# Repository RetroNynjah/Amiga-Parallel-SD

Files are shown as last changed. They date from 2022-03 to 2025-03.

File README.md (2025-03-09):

# Retroninja Amiga Parallel SD

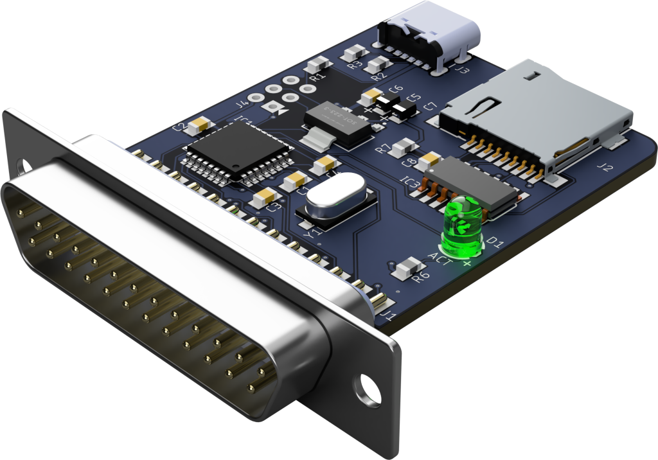
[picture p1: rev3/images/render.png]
Render
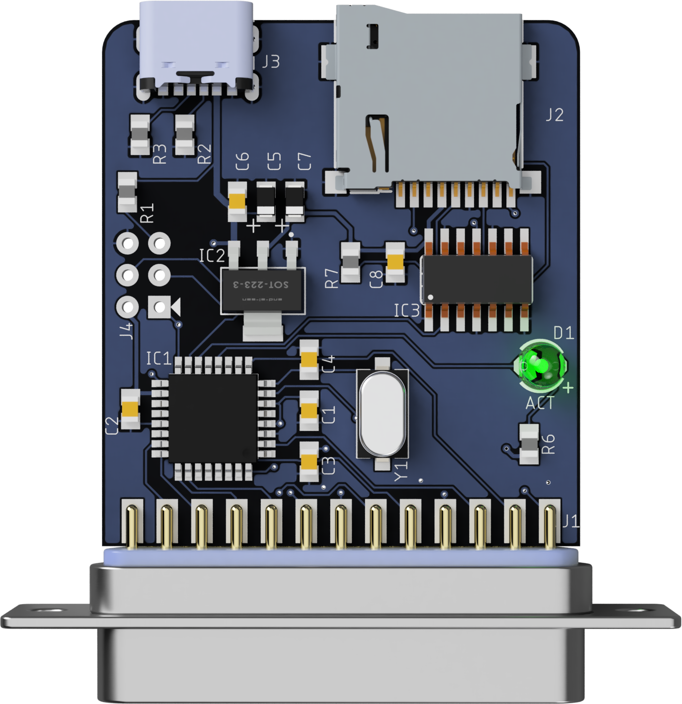
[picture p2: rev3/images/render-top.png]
Render top
<br/>

MicroSD SPI interface based on a design concept by [Niklas Ekström](https://github.com/niklasekstrom/amiga-par-to-spi-adapter)

It's quite useful for transferring files to and from the Amiga 500 and other Amiga models that doesn't have a PCMCIA interface or any other interface for mass storage devices.  
The difference from some previous designs is that this version is very small and fully integrated.  
It has a USB-C connector for power because the parallel port doesn't supply any power. It should be possible to take power from another port such as the floppy port or maybe even the joystick ports(?) if you have an adapter for that but I prefer to use an external power source.

A suitable Amiga driver for this device was developed by Niklas Ekström. The source code and a compiled driver can be found in his [release archive](https://github.com/niklasekstrom/amiga-par-to-spi-adapter/releases).

Revision 3 of this board is using a different connection of the activity LED compared to earlier designs and revisions so rev 3 boards needs a different firmware for the LED to work. Jörgen Bilander has created a suitable firmware for this. The source code is available in [his repository](https://github.com/jbilander/amiga-par-to-spi-adapter). I have precompiled hex files for all variants in the [firmware](rev3/firmware) folder.

I have designed a 3D-printable enclosure which can be found at https://www.thingiverse.com/thing:6799759/files

## Installation
You need the spisd.device driver in Devs: and the [fat95 DOS handler](https://aminet.net/package/disk/misc/fat95) in L: and you need a suitable mount file, either in Devs:DOSDrivers for auto-mounting or in a convenient location for mounting on demand.  
For WB1.3/2.0 installations you need to add the device settings to the file Devs:MountList instead. You also need to run the mount command to mount the device using the settings in your mount list. Type `mount SD0:` to mount the device or add that to your startup-sequence to have it available at all times.  
I have a suitable mount file (SD0) and MountList settings in the [amiga](amiga/) folder in this Github repository.

> [!CAUTION]
> Do **NOT** insert or remove the device while the computer is running.

## BOM
|Parts|Device|Value|Qty|Comment
|-----|-----|-----|-----|-----|
|C1, C2, C6, C8|Ceramic capacitor 0805|100nF|4||
|C5, C7|Tantalum capacitor 0805|10uF/10V|2||
|C3, C4|Ceramic capacitor 0805|30pF|2||
|R1, R7|Resistor 0805|10kΩ|2||
|R2, R3|Resistor 0805|5.1kΩ|2||
|R4|Resistor 0805|100R|1|Rev 2 only|
|R5|Resistor 0805|100kΩ|1|Rev 2 only|
|R6|Resistor 0805|560R|1||
|IC1|MCU 32-TQFP|ATmega328|1||
|IC2|3.3V regulator SOT-223|1117-3.3|1||
|IC3|Quad bus buffer|74LVC125A|1||
|Q1|P-channel MOSFET SOT-23|BSS84|1|Rev 2 only|
|D1|LED|3mm LED|1||
|Y1|16MHz Crystal|ECS-160-20-3X-TR|1||
|J1|D-Sub Male|25-pin|1||
|J2|8-pin push-push MicroSD connector|Würth 693071020811|1||
|J3|USB-C Connector|Molex 2171750001|1||
|J4|ICSP-6 header (optional)|2x3-pin|1||

#### Some notes about the parts in the BOM
The crystal capacitors C3 and C4 should ideally match your crystal but in general it will work just fine with any capacitors around 20-30pF.

The voltage regulator is a 3.3V 1117 type regulator. These are available from plenty of manufacturers and the exact part numbers vary. Use whatever you can find.

The D-sub can have either through hole pins or solder cups. I prefer solder cups as they provide a tighter fit over the PCB edge.

The ICSP header is a regular 2x3 pin-header. I usually leave it out and use a 2x3 pogo pin adapter for uploading firmware. It's also posible to just stick a connector into the slots and push it gently sideways to make contact while uploading the firmware.

The original design was based around an ATmgea328-based Arduino Nano module but with this board a wide range of ATmega328/168/88/48 MCU:s can be used, at least with the current firmware version. Use whatever you can lay your hands on for the day. ATmega48/88/168/328 A/P/PA/PB should all work. ATmega328P is recommended.

A compatible MicroSD connector can be found on AliExpress at a much better price than the Würth connector: https://www.aliexpress.com/item/32802051702.html

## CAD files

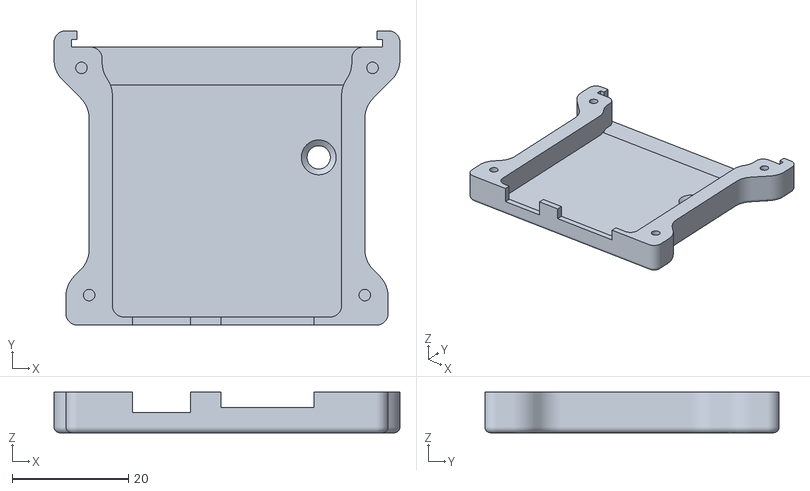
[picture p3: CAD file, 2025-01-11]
rev3/enclosure/top.stl
59.6 x 50.7 x 7.00

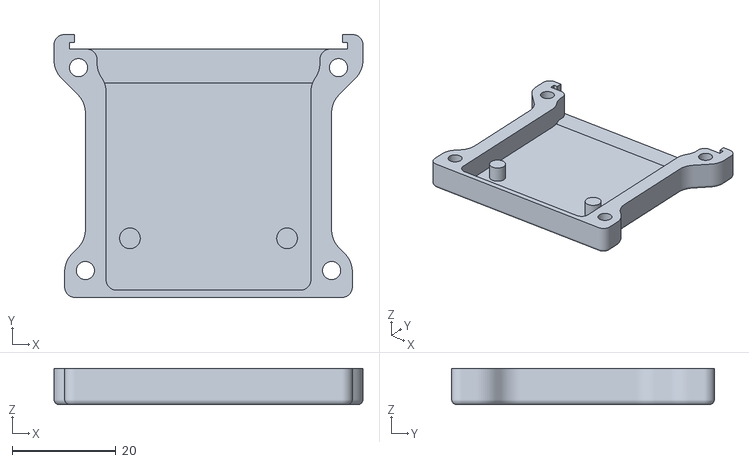
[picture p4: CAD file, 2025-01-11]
rev3/enclosure/bottom.stl
59.6 x 50.7 x 7.00

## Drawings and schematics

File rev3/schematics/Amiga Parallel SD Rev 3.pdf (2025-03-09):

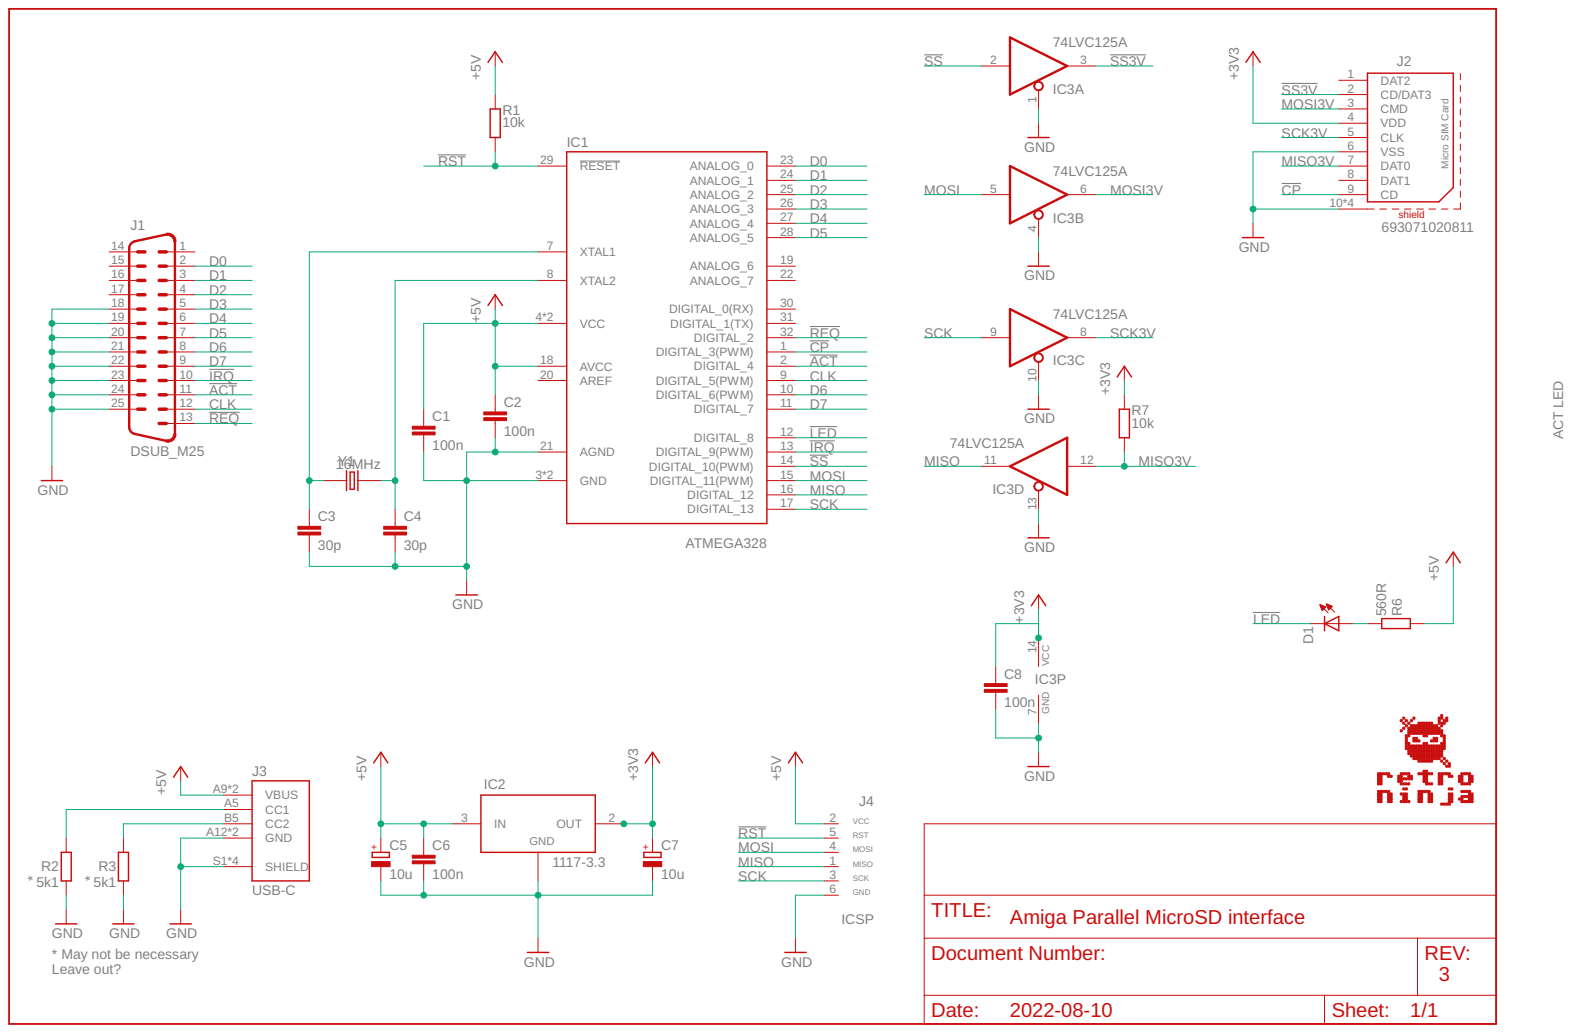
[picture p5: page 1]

Amiga Parallel MicroSD interface

* May not be necessary
Leave out?

Document Number: | REV: 3

Date: 2022-08-10 | Sheet: 1/1

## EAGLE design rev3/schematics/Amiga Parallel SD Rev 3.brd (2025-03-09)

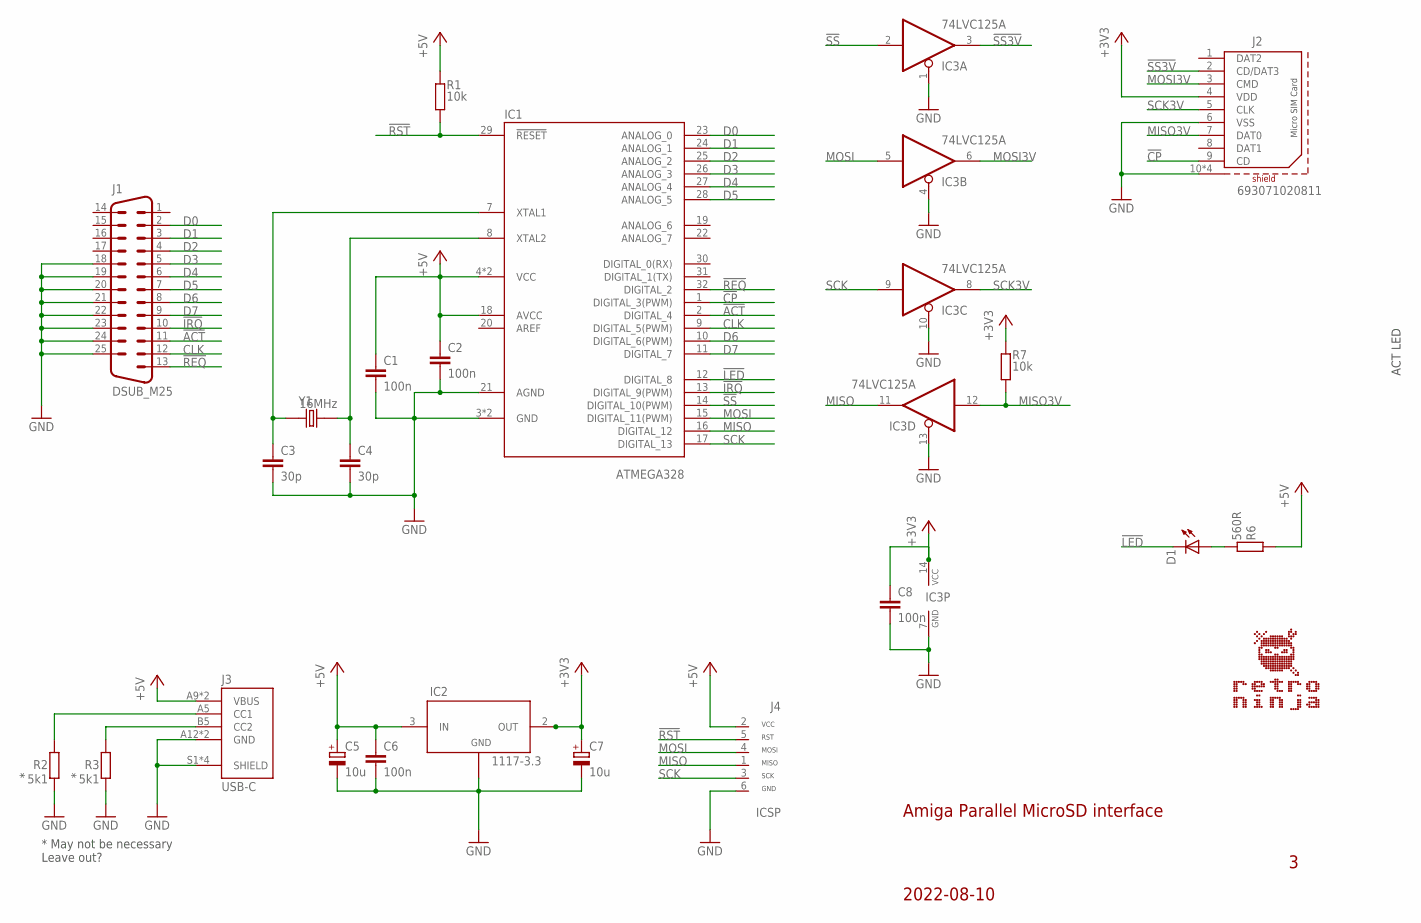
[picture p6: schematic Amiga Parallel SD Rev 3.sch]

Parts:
C1, C2, C6, C8: 100n; C0805
C3, C4: 30p; C0805
C5, C7: 10u; TANTALUM_0805
D1: LED_3MM_GREEN; LED3MM_GREEN
IC1: ATMEGA328; TQFP-32
IC2: 1117-3.3; SOT-223
IC3: 74LVC125A; SO14
J1: DSUB_M25; DSUB_M25D
J2: 693071020811
J3: USB-C; MOLEX_2171750001
J4: ICSP; HEADER_2X3_ALT
R1, R7: 10k; R0805
R2, R3: 5k1; R0805
R6: 560R; R0805
Y1: 16MHz; CRYSTAL_SMD-2_7X4X2.3

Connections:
!ACT: IC1.2 (DIGITAL_4), J1.11
!CP: IC1.1 (DIGITAL_3(PWM)), J2.9 (CD)
!IRQ: IC1.13 (DIGITAL_9(PWM)), J1.10
!LED: D1.K (C), IC1.12 (DIGITAL_8)
!REQ: IC1.32 (DIGITAL_2), J1.13
!RST: IC1.29 (!RESET), J4.5 (RST), R1.2
!SS: IC1.14 (DIGITAL_10(PWM)), IC3.2 (I)
!SS3V: IC3.3 (O), J2.2 (CD/DAT3)
+3V3: C7.+, C8.1, IC2.2 (OUT), IC2.4, IC3.14 (VCC), J2.4 (VDD), R7.1
+5V: C1.1, C2.1, C5.+, C6.1, IC1.4 (VCC), IC1.6 (VCC), IC1.18 (AVCC), IC2.3 (IN), J3.A9 (VBUS), J3.B9 (VBUS), J4.2 (VCC), R1.1, R6.2
A5: J3.A5 (CC1), R2.2
B5: J3.B5 (CC2), R3.2
CLK: IC1.9 (DIGITAL_5(PWM)), J1.12
D0: IC1.23 (ANALOG_0), J1.2
D1: IC1.24 (ANALOG_1), J1.3
D2: IC1.25 (ANALOG_2), J1.4
D3: IC1.26 (ANALOG_3), J1.5
D4: IC1.27 (ANALOG_4), J1.6
D5: IC1.28 (ANALOG_5), J1.7
D6: IC1.10 (DIGITAL_6(PWM)), J1.8
D7: IC1.11 (DIGITAL_7), J1.9
GND: C1.2, C2.2, C3.2, C4.2, C5.-, C6.2, C7.-, C8.2, IC1.3 (GND), IC1.5 (GND), IC1.21 (AGND), IC2.1 (ADJ/GND), IC3.1 (OE), IC3.4 (OE), IC3.7 (GND), IC3.10 (OE), IC3.13 (OE), J1.18, J1.19, J1.20, J1.21, J1.22, J1.23, J1.24, J1.25, J2.6 (VSS), J2.10 (SHIELD), J2.11 (SHIELD), J2.12 (SHIELD), J2.13 (SHIELD), J3.A12 (GND), J3.B12 (GND), J3.S1 (SHIELD), J3.S2 (SHIELD), J3.S3 (SHIELD), J3.S4 (SHIELD), J4.6 (GND), R2.1, R3.1
MISO: IC1.16 (DIGITAL_12), IC3.11 (O), J4.1 (MISO)
MISO3V: IC3.12 (I), J2.7 (DAT0), R7.2
MOSI: IC1.15 (DIGITAL_11(PWM)), IC3.5 (I), J4.4 (MOSI)
MOSI3V: IC3.6 (O), J2.3 (CMD)
unnamed: D1.A, R6.1
unnamed: C4.1, IC1.8 (XTAL2), Y1.1
unnamed: C3.1, IC1.7 (XTAL1), Y1.2
SCK: IC1.17 (DIGITAL_13), IC3.9 (I), J4.3 (SCK)
SCK3V: IC3.8 (O), J2.5 (CLK)

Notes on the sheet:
* May not be necessary Leave out?
ACT LED
Amiga Parallel MicroSD interface
2022-08-10

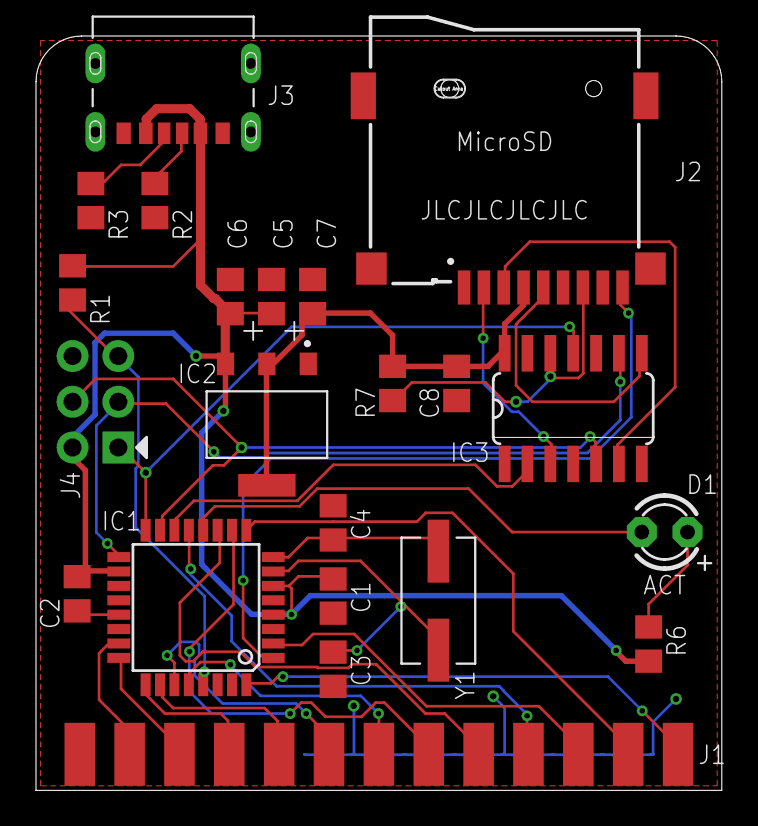
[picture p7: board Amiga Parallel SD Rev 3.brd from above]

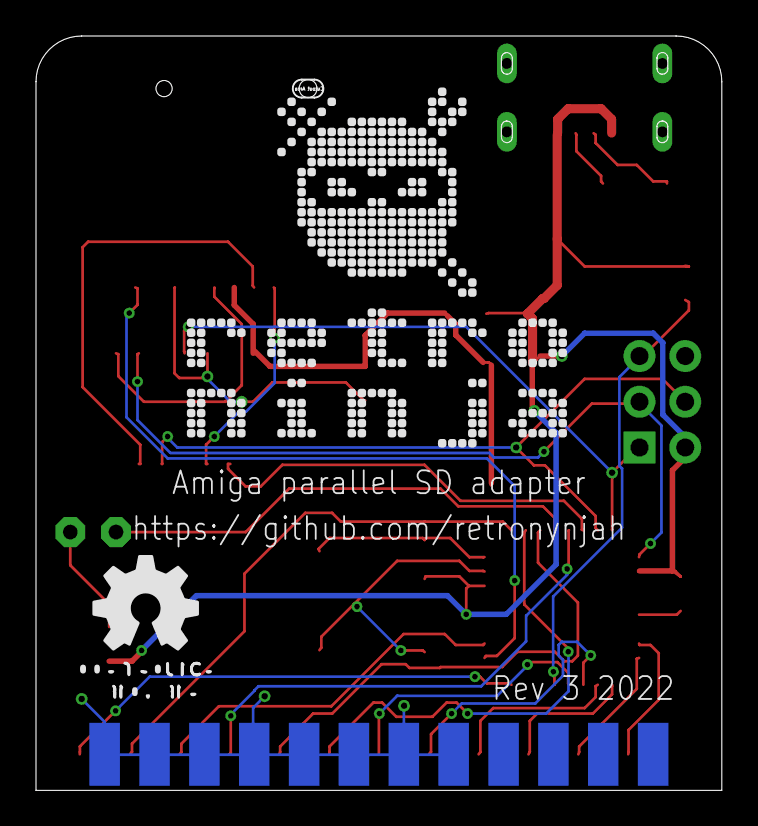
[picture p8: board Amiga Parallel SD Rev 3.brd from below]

Board: 2 copper layers, 38.1 x 41.9 mm, 24 parts (2 on the bottom side), 31 nets.

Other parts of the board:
U$1: RETRONINJA_20MM
U$2: OSHW_8MM

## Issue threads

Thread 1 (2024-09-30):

Hi! Not an issue really... is there a STL to 3d print a cover??

f-bone, 2024-09-30:
I would love to print a cover for this... is there an stl available??

thank you for all your efforts!

br,
george

RetroNynjah, 2024-10-15:
Really sorry about the late answer.
I haven't touched this project in a few years and I kind of dropped the ball.
I made a rev 3 design with better LED functionality before I lost interest but I never ordered any rev 3 boards so it's untested and I didn't publish it.

There is an stl, or at least there was. I have tried to recreate it but I made a very weird CAD design without separate components. Turning various features on or off makes the part either a top half or a bottom half and I don't rememer which features. Stupid design...
Anyway, I've generated stl files now but I haven't tried to print them.
I can email them to you if you want to try them and if they work, I can publish them. Do you have an email address that you can share?
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

f-bone, 2024-10-16:
looks really good! first of all thank you for your reply. I'd be happy to try the files and let you know. I could even order rev3 boards if you wish and see how that works out too! another.reality@gmail.com

Closed 2025-01-11.

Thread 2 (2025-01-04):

Sticker?

arleybls, 2025-01-04:
Do you have the top and bottom sticker template,?
Cheers

arleybls, 2025-01-07:
for the enclosure, the bottom and top stickers with the indications of open hardware, sd, power etc.

RetroNynjah, 2025-01-11:
I've added the sticker svg files to the enclosure folder.
These were quite specific for my builds with colors matching my plastic and so on so you would have to adjust them for your builds or it will look weird.

arleybls, 2025-01-23:
thank you

Closed 2025-01-11.

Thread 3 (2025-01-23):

Release v2.2 compatible?

arleybls, 2025-01-23:
Is this compatible with rev 2.2 of the spi driver? I built already 3 , programmed mutilpe times a 88a and always get unrecognized.

RetroNynjah, 2025-01-24:
I haven't tested it with version 2.2. I think I tried 2.0 or possibly 2.1 the last time I fiddled with this.
I know that it was quite picky with the SD cards that I tried so perhaps try a different SD card model?

arleybls, 2025-01-26:
it works with 2.0 bugfix release, could get to work with 2.2. And got also problems with fat32, but managed to get working with fat (so <4g partitions). Thank you for your support

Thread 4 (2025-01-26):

ACT circuit problem

arleybls, 2025-01-26:
I having a hardtime managing to get the ACT led working,  out of five built only 2 actually working. What could it be? bad batch of bs884? Can i just remove r4, r5 and q1 and solder jump drain and source pads to use is a power on led?

Could you also change the footprint of the crystal to a HC49S, much more common and it fits perfectly

RetroNynjah, 2025-01-26:
I will not change the design to suite your parts bin. The parts I have used are easy enough to source.
The project is open source so that you can change it yourself if it doesn't suite you.

Do the units with non working LEDs have something in common?
Do they use a different firmware version or something?

On a side note, I wasn't happy with the activity LED on this revision of the board because the activity LED stays on after powering off the Amiga. I made a modification on my boards that connects the LED to a free AVR pin and used a modified firmware by jbilander.
https://github.com/jbilander/amiga-par-to-spi-adapter/tree/master/avr
This firmware hasn't been updated to reflect the changes made by Niklas Ekström but the changes that jbilander did to the old firmware can be done to the newer firmwares.
I also designed a new revision of the PCB with this single change but never got around to test it and therefore haven't published it either.
The hardware modification is to connect R4 to ATmega pin 12 instead of the activity line on the parallel port like in this picture:
[Image](https://github.com/user-attachments/assets/fd99040f-ff76-4aa6-8452-da88336af732)//

arleybls, 2025-01-26:
"Do the units with non working LEDs have something in common?
Do they use a different firmware version or something?"
- no, they use exactly the same parts and firmware.

arleybls, 2025-01-29:
I have forked the project and will implement the changes and test it. Altough it will be done in kicad :/
Any idea on the ACT circuit and why would be firing as expected? I confirmed the sd card still work just the led is off on those not working.

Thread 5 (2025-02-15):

Arduino as ISP help :)

f-bone, 2025-02-15:
Hi there!

I am trying to flash the board using Arduino as ISP but as a category 5 noob I find it a bit difficult to give the correct command.

Reading around the net I put this command together:
avrdude.exe -C avrdude.conf -v -p atmega328p -c arduino -PCOM3 -U efuse:w:0xFD:m -U hfuse:w:0xDE:m -U lfuse:w:0xFF:m -U flash:w:amiga-par-to-spi-328.hex (renamed my file to amiga.hex for simplicity)

I have connected the Arduino UNO pins to the Parallel-to-SD board one-to-one from D10 to D13 to the corresponding 6 icsp pins on the other side (using 5V, the SD board led turns on). I am also using the default .conf file I found in tools folder of Arduino IDE.

SD board pins:

1 - 2
3 - 4
5 - 6

When I give the command I get:
"C:\Users\George\AppData\Local\Arduino15\packages\arduino\tools\avrdude\6.3.0-arduino17\bin>avrdude.exe -C avrdude.conf -v -p atmega328p -c arduino -PCOM3 -U efuse:w:0xFD:m -U hfuse:w:0xDE:m -U lfuse:w:0xFF:m -U flash:w:amiga.hex

avrdude.exe: Version 6.3-20190619
             Copyright (c) 2000-2005 Brian Dean, http://www.bdmicro.com/
             Copyright (c) 2007-2014 Joerg Wunsch

             System wide configuration file is "avrdude.conf"

             Using Port                    : COM3
             Using Programmer              : arduino
             AVR Part                      : ATmega328P
             Chip Erase delay              : 9000 us
             PAGEL                         : PD7
             BS2                           : PC2
             RESET disposition             : dedicated
             RETRY pulse                   : SCK
             serial program mode           : yes
             parallel program mode         : yes
             Timeout                       : 200
             StabDelay                     : 100
             CmdexeDelay                   : 25
             SyncLoops                     : 32
             ByteDelay                     : 0
             PollIndex                     : 3
             PollValue                     : 0x53
             Memory Detail                 :

                                      Block Poll               Page                       Polled
               Memory Type Mode Delay Size  Indx Paged  Size   Size #Pages MinW  MaxW   ReadBack
               ----------- ---- ----- ----- ---- ------ ------ ---- ------ ----- ----- ---------
               eeprom        65    20     4    0 no       1024    4      0  3600  3600 0xff 0xff
               flash         65     6   128    0 yes     32768  128    256  4500  4500 0xff 0xff
               lfuse          0     0     0    0 no          1    0      0  4500  4500 0x00 0x00
               hfuse          0     0     0    0 no          1    0      0  4500  4500 0x00 0x00
               efuse          0     0     0    0 no          1    0      0  4500  4500 0x00 0x00
               lock           0     0     0    0 no          1    0      0  4500  4500 0x00 0x00
               calibration    0     0     0    0 no          1    0      0     0     0 0x00 0x00
               signature      0     0     0    0 no          3    0      0     0     0 0x00 0x00

             Programmer Type : Arduino
             Description     : Arduino
             Hardware Version: 3
             Firmware Version: 4.4
             Vtarget         : 0.3 V
             Varef           : 0.3 V
             Oscillator      : 28.800 kHz
             SCK period      : 3.3 us

avrdude.exe: AVR device initialized and ready to accept instructions

Reading | ################################################## | 100% 0.00s

avrdude.exe: Device signature = 0x1e950f (probably m328p)
avrdude.exe: safemode: lfuse reads as 0
avrdude.exe: safemode: hfuse reads as 0
avrdude.exe: safemode: efuse reads as 0
avrdude.exe: NOTE: "flash" memory has been specified, an erase cycle will be performed
             To disable this feature, specify the -D option.
avrdude.exe: erasing chip
avrdude.exe: reading input file "0xFD"
avrdude.exe: writing efuse (1 bytes):

Writing |                                                    | 0% 0.00s ***failed;
Writing | ################################################## | 100% 0.09s

avrdude.exe: 1 bytes of efuse written
avrdude.exe: verifying efuse memory against 0xFD:
avrdude.exe: load data efuse data from input file 0xFD:
avrdude.exe: input file 0xFD contains 1 bytes
avrdude.exe: reading on-chip efuse data:

Reading | ################################################## | 100% 0.02s

avrdude.exe: verifying ...
avrdude.exe: verification error, first mismatch at byte 0x0000
             0x00 != 0xfd
avrdude.exe: verification error; content mismatch

avrdude.exe: safemode: lfuse reads as 0
avrdude.exe: safemode: hfuse reads as 0
avrdude.exe: safemode: efuse reads as 0
avrdude.exe: safemode: efuse changed! Was fd, and is now 0
Would you like this fuse to be changed back? [y/n] y
avrdude.exe: stk500_recv(): programmer is not responding

AND then the following error repeats"

"avrdude.exe: stk500_cmd(): programmer is out of sync"

apologies for the trouble I'd really appreciate it if you could show me the way only if it takes max 2minutes of your time. If more than that is needed dont worry about it at all I will order a usbasp programmer!

thank you for everything
george

RetroNynjah, 2025-02-16:
What I can see is that it is able to read the chip ID so something must be working but it fails to write the fuses for some reason.
I'm sorry but I can't be of much help with Arduino as ISP. I have never used that. I'm only using usbasp.

f-bone, 2025-02-26:
thank you very much!! I will get the programmer they are really cheap. Keep up the good work!

f-bone, 2025-03-01:
done using usbasp! used zadig to install the driver under win11. thank you!

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

f-bone, 2025-03-01:
ok now the LED doesn't turn on and I am getting message "bad number" - I have the unofficial v3 with the jumper.. maybe I flashed the wrong file?

RetroNynjah, 2025-03-07:
Sorry for a very late reply.

About the LED...
Which firmware did you use?
If I remember correctly, this one should work: https://github.com/jbilander/amiga-par-to-spi-adapter/tree/master/avr
It adds support for activity LED at PB0 (D8).

I don't know what that error message means.
Where and when do you get that message?

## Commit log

2022-03-16 Uploading mount file
2024-10-16 Update README.md
    Updated software release link
    Added link for 3D-printable enclosure
2025-01-11 Enclosure added
    [bottom.stl, top.stl]
2025-03-09 Revision 3 published
    The previously unreleased rev 3 is finally published
    [Amiga Parallel SD Rev 3.brd, Amiga Parallel SD Rev 3.sch, bottom.stl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]

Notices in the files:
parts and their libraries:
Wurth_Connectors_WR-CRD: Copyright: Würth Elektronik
